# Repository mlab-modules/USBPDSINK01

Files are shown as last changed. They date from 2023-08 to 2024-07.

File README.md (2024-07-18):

# USBPDSINK01 - USB Power Delivery sink controller

The [MLAB](https://www.mlab.cz) module [USBPDSINK01](https://www.mlab.cz/module/USBPDSINK01) is a powerful module containing the [STUSB4500](https://www.st.com/en/interfaces-and-transceivers/stusb4500.html) [power-delivery sink controller](https://en.wikipedia.org/wiki/USB_hardware#USB_Power_Delivery). The module is designed to provide a flexible and reliable solution for various applications requiring USB power delivery PD2 and PD3 protocols. 

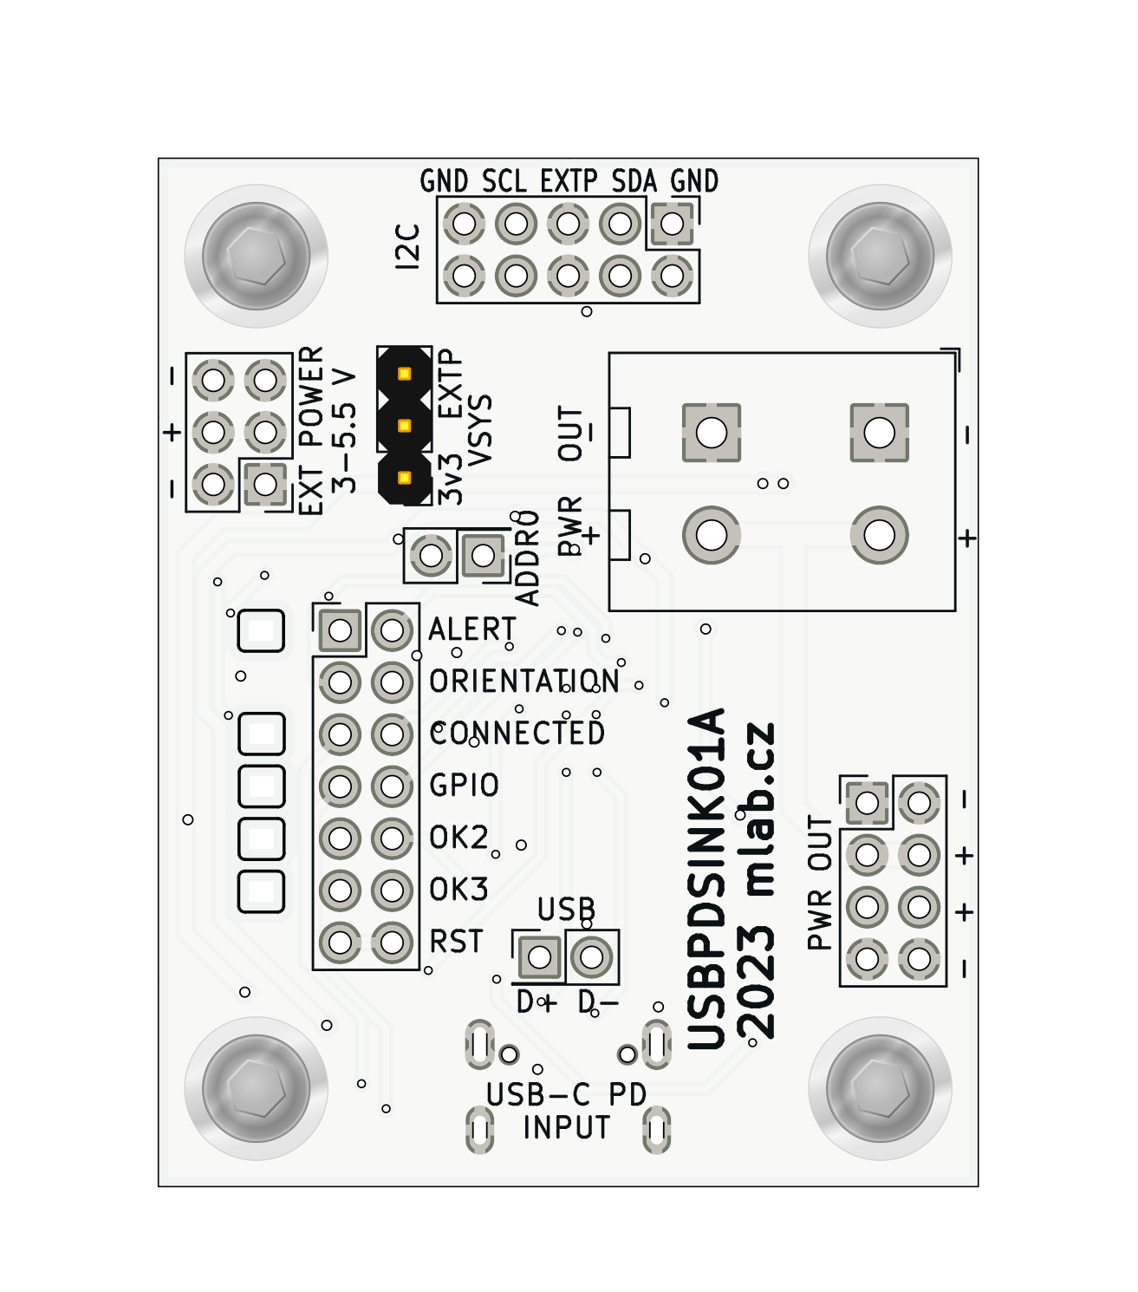
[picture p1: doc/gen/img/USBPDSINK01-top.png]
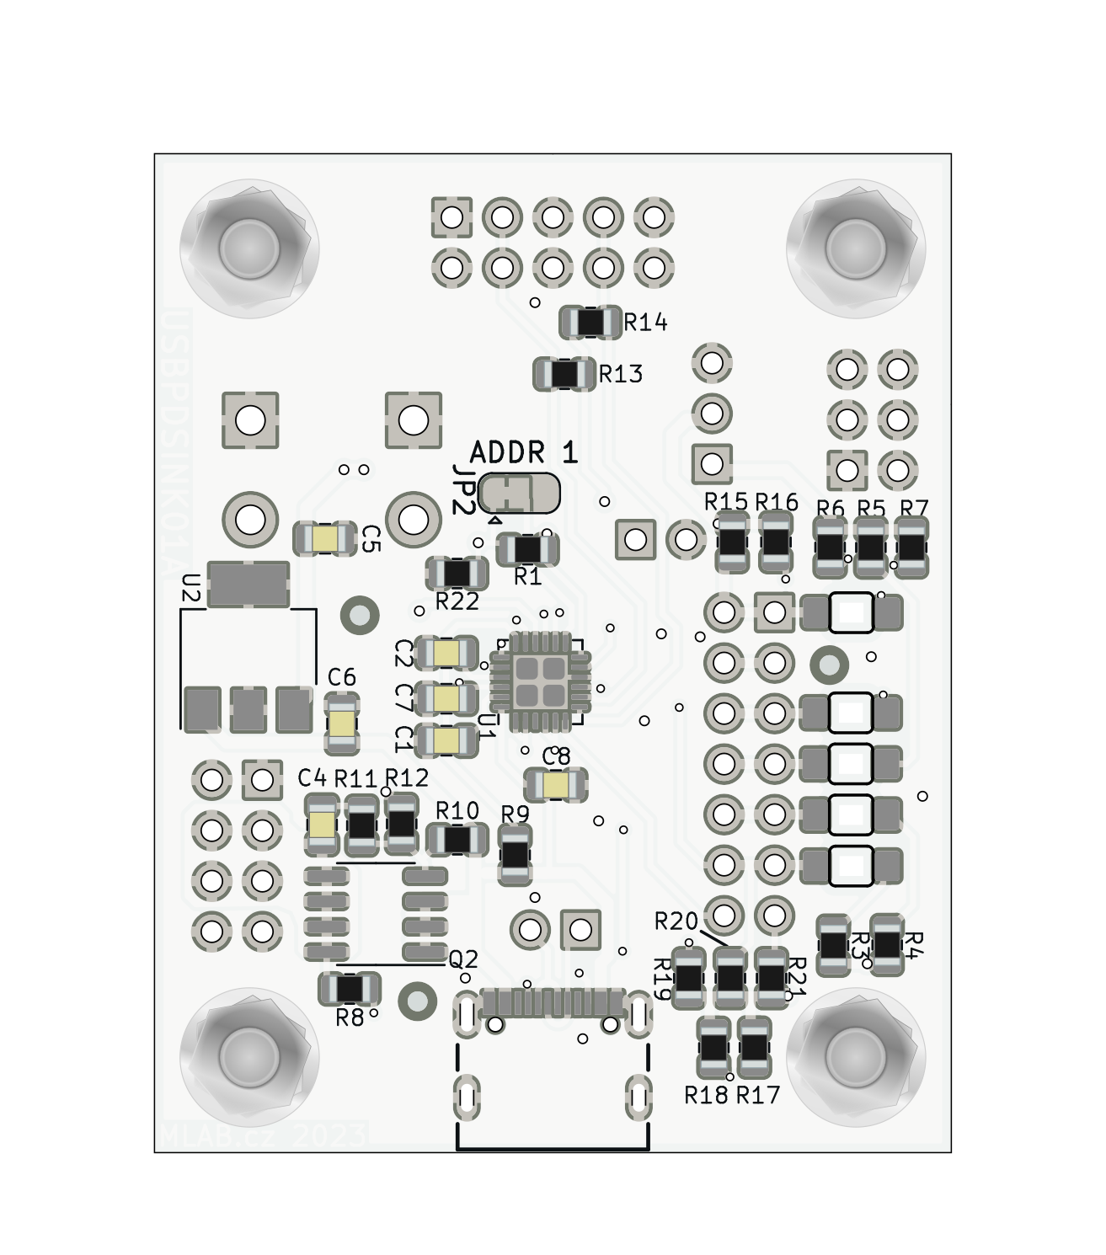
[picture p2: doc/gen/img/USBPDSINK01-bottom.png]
  

## Specifications

[STUSB4500](https://www.st.com/en/interfaces-and-transceivers/stusb4500.html) is a USB-C PD controller for Power Sinks / UFP (on the device side). It is certified by the USB-IF consortium for [USB Type-C](https://www.usb.org/usb-type-c) and [USB Power Delivery](https://www.usb.org/usb-charger-pd) applications (USB-C & USB PD).

### Module Features

- **USB-C Input:** The module accepts power through the USB-C connector.
- **Power Output:** The output is led to a pin header and also to a WAGO terminal block to high-power tool-free connection of powered devices.
- **Indicator Pins with LED:** Some status pins contain LEDs, and these signals are connected to the pin header.
- **Pull-up Resistors:** The module has pull-up resistors on the output signals for fast implementation into your system. PullUp voltage can be attached to header pins or can be used internal 3v3.
- **Integrated LDO:** The module is equipped with an integrated LDO for powering pullups and LED (no output).
- **External Power Supply:** The VSYS power can also be attached externally.
- **Communication via I2C:** The module communicates via I2C bus.
- **Key Features of [STUSB4500](https://www.st.com/en/interfaces-and-transceivers/stusb4500.html):**
  - Auto-run USB Type-C™ and USB PD sink controller handling and detection
  - Dead battery mode support
  - Up to 3 configurable sink PDO profiles (with permanent memory)
  - Integrated VBUS switching gates (PMOS transistor)
  - Integrated VBUS voltage monitoring
  - Internal and/or external VBUS discharge paths (for high capacitance networks)
  - Short-circuit protection on VBUS pins (22 V)
  - High-voltage capability on VBUS pins (28 V)
  - Dual power supply (VSYS and/or VDD): VDD = [4.1 V; 22 V] or VSYS = [3.0 V; 5.5 V]
  - Accessory mode support
  - Temperature range: -40 °C to 105 °C
  - ESD: 3 kV HBM - 1.5 kV CDM
  - Certified: USB Type-C™ rev 1.2, USB PD rev 2.0 (Official Test ID: TID #1000133)
  - Interoperable with USB PD rev 3.0

### Pinout and Their Meaning

- **ALERT:** Notification of various states and events.
- **USB-C orientation:** Indication of the connected side of the USB-C cable.
- **CONNECTED:** Cable connection indication.
- **GPIO:** General input/output pin, configurable for various purposes.
- **OK2 & OK3:** Pins that are active when the corresponding PDO is selected. Can indicate the selected voltage.
- **RESET:** Pin for resetting the USB-PD controller.

## Possible Applications
The MLAB module USBPDSINK01 is ideal for a wide range of applications, including:

- **Device Charging:** Fast and efficient charging of devices with high battery capacity. The module allows automatic negotiation of higher voltage from the source (>5V) up to 100W (20V@5A), ensuring the optimal charging profile for various types of batteries.

- **Scientific and Industrial Applications:** Flexible power and control for various scientific and industrial applications. With the ability to configure up to three sink PDO profiles, the module can be tailored to specific research or experiment needs.

- **Development and Testing:** The module can be used as part of development and testing stations for various products. With integrated VBUS switching gates and short-circuit protection up to 22 V, the module offers a robust and safe solution for testing and tuning.

- **Universal Power Source:** The module can serve as a universal power source for various devices, including charges, speakers, machines, or other electronic devices that require high-wattage power sources.

<p align="center">
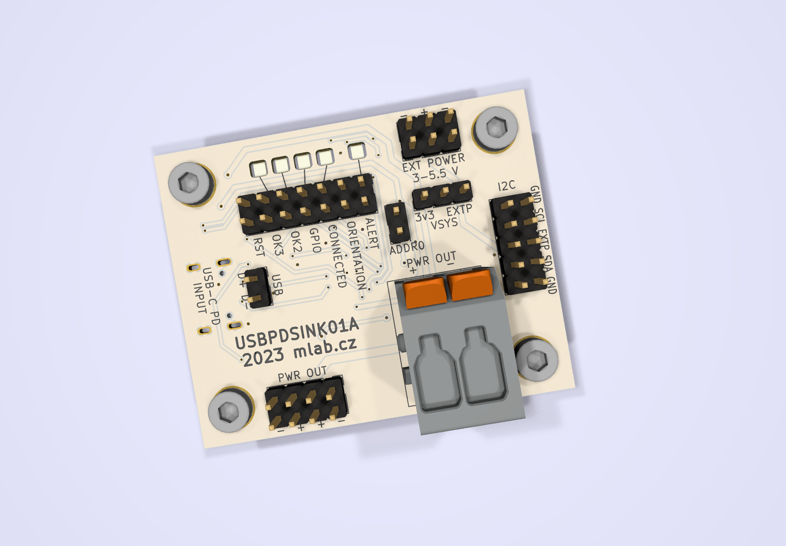
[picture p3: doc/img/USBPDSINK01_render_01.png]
 
</p>

## Schematics



## Documentation
- [STUSB4500 Datasheet](https://www.st.com/resource/en/datasheet/stusb4500.pdf)

## Conclusion

The MLAB module USBPDSINK01 represents a robust and flexible solution for various applications requiring USB power delivery. With the integrated STUSB4500 controller, advanced features, and a wide range of possible applications, this module is the ideal choice for developers and engineers looking for a reliable and powerful solution.

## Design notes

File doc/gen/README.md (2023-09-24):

# PCB

Board size: 45.49x52.95 mm (1.79x2.08 inches)

- This is the size of the rectangle that contains the board
- Thickness: 1.6 mm (63 mils)
- Material: FR4
- Finish: None
- Layers: 2
- Copper thickness: 35 µm

Solder mask: TOP / BOTTOM

- Color: Top: White / Bottom: Green

Silk screen: TOP / BOTTOM

- Color: Black

Stackup:

| Name | Type | Color | Thickness | Material | Epsilon_r | Loss tangent |
|---|---|---|---|---|---|---|
| F.SilkS | Top Silk Screen | Black | | | | |
| F.Paste | Top Solder Paste | | | | | |
| F.Mask | Top Solder Mask | White | 10 | | | |
| F.Cu | copper | | 35 | | | |
| dielectric 1 | core | FR4 natural | 1510 | FR4 | 4.5 | 0.020 |
| B.Cu | copper | | 35 | | | |
| B.Mask | Bottom Solder Mask | Green | 10 | | | |
| B.Paste | Bottom Solder Paste  | | | | | |
| B.SilkS | Bottom Silk Screen | Black | | | | |

# Important sizes

Clearance: 0.2 mm (8 mils)

Track width: 0.25 mm (10 mils)

- By design rules: 0.0 mm (0 mils)

Drill: 0.4 mm (16 mils)

- Vias: 0.4 mm (16 mils) [Design: 0.4 mm (16 mils)]
- Pads: 0.65 mm (26 mils)
- The above values are real drill sizes, they add 0.1 mm (4 mils) to plated holes (PTH)

Via: 0.5/0.3 mm (20/12 mils)

- By design rules: 0.5/0.3 mm (20/12 mils)
- Micro via: yes [0.2/0.1 mm (8/4 mils)]
- Buried/blind via: yes
- Total: 48 (thru: 48 buried/blind: 0 micro: 0)

Outer Annular Ring: 0.05 mm (2 mils)

- By design rules: 0.05 mm (2 mils)

Eurocircuits class: 6D
- Using min drill 0.25 mm for an OAR of 0.13 mm

# General stats

Components count: (SMD/THT)

- Top: 0/12 (THT)
- Bottom: 40/0 (SMD)

Defined tracks:

- 0.25 mm (10 mils)
- 0.3 mm (12 mils)
- 0.5 mm (20 mils)
- 0.6 mm (24 mils)

Used tracks:

- 0.25 mm (10 mils) (59) defined: yes
- 0.3 mm (12 mils) (174) defined: yes
- 0.5 mm (20 mils) (37) defined: yes
- 0.6 mm (24 mils) (44) defined: yes
- 1.0 mm (39 mils) (4) defined: no

Defined vias:

- 0.5/0.3 mm (20/12 mils)
- 0.8/0.4 mm (31/16 mils)

Used vias:

- 0.5/0.3 mm (20/12 mils) (Count: 28, Aspect: 3.2 A) defined: yes
- 0.8/0.4 mm (31/16 mils) (Count: 20, Aspect: 2.0 A) defined: yes

Holes (excluding vias):

- 0.65 mm (26 mils) (2)
- 1.0 mm (39 mils) (45)
- 1.4 mm (55 mils) (4)
- 3.0 mm (118 mils) (4)

Oval holes:

- 0.6x1.4 mm (24x55 mils) (2)
- 0.6x1.7 mm (24x67 mils) (2)

Drill tools (including vias and computing adjusts and rounding):

- 0.4 mm (16 mils) (28)
- 0.5 mm (20 mils) (20)
- 0.65 mm (26 mils) (2)
- 0.7 mm (28 mils) (4)
- 1.1 mm (43 mils) (45)
- 1.5 mm (59 mils) (4)
- 3.1 mm (122 mils) (4)

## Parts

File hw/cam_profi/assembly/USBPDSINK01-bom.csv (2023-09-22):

Component | Description | Part | References | Value | Footprint | Quantity Per PCB | Datasheet | mfpn | mpn | ust_id | sim.pins | sim.type
1 | Unpolarized capacitor, small symbol | C_Small | C4 | 100n | C_0805_2012Metric | 1 | ~ | C0805 100n | C0805 100n | 5c70984712875079b91f8b4c
2 | Unpolarized capacitor, small symbol | C_Small | C1C2C7C8 | 1u | C_0805_2012Metric | 4 | ~ | C0805 1u | C0805 1u | 5c70984712875079b91f8b50
3 | Unpolarized capacitor, small symbol | C_Small | C5C6 | 10u | C_0805_2012Metric | 2 | ~ | C0805 10u | C0805 10u | 5c70984712875079b91f8b53
4 | Light emitting diode | LED | D3 | BLUE | LED_1206_mill | 1 | ~ | KPTR-3216QBC-D | KPTR-3216QBC-D | 650b4b9e462c6d9e7205459d
5 | Light emitting diode | LED | D5 | GREEN | LED_1206_mill | 1 | ~ | KPTR-3216CGCK | KPTR-3216CGCK | 64ab2ec176c82a1d3b57875b
6 | Light emitting diode | LED | D1D4 | RED | LED_1206_mill | 2 | ~ | KPTR-3216SURCK | KPTR-3216SURCK | 64ab2fba76c82a1d3b57877d
7 | Light emitting diode | LED | D2 | YELLOW | LED_1206_mill | 1 | ~ | KPTR-3216SYCK | KPTR-3216SYCK | 650b4b13462c6d9e7205456a
8 | 2x03 2.54 mm pitch header, 2 pins next to each other are connected | HEADER_2x03_PARALLEL | J4 | HEADER_2x03_PARALLEL | PinHeader_2x03_P2.54mm_Vertical | 1
9 | 2x04 2.54 mm pitch header, 2 pins next to each other are connected | HEADER_2x04_PARALLEL | J3 | HEADER_2x04_PARALLEL | PinHeader_2x04_P2.54mm_Vertical | 1
10 | 2x05 2.54 mm pitch header, 2 pins next to each other are connected | HEADER_2x05_PARALLEL | J2 | HEADER_2x05_PARALLEL | PinHeader_2x05_P2.54mm_Vertical | 1
11 | 2x07 2.54 mm pitch header, 2 pins next to each other are connected | HEADER_2x07_PARALLEL | J6 | HEADER_2x07_PARALLEL | PinHeader_2x07_P2.54mm_Vertical | 1
12 | USB 2.0-only Type-C Receptacle connector | USBC_USB4105-GF-A | J1 | USBC_USB4105-GF-A | USBC GCT_USB4105-GF-A | 1 |  | USB4105-GF-A | USB4105-GF-A | 5fa0f94612875025b397795e
13 | 1x02 2.54 mm pitch header | HEADER_1x02 | J7 | WAGO_2604-3102 | TerminalBlock_WAGO_2604-3102_1x02_P5.00mm_Vertical | 1 |  | 2604-3102 | 2604-3102
14 | Jumper, 2-pole, open | Jumper_2_Open | JP1 | Jumper_2_Open | PinHeader_2x01_P2.54mm_Vertical | 1 | ~
15 | Jumper, 3-pole, pins 1+2 closed/bridged | Jumper_3_Bridged12 | JP2 | Jumper_3_Bridged12 | SolderJumper-3_P1.3mm_Bridged12_RoundedPad1.0x1.5mm | 1 | ~
16 | Jumper, 3-pole, pins 1+2 closed/bridged | Jumper_3_Bridged12 | JP3 | Jumper_3_Bridged12 | PinHeader_1x03_P2.54mm_Vertical | 1 | ~
17 | P-MOSFET transistor, drain/source/gate, 40V, 9A, 12mOhm | IRF7469PbF | Q2 | IRF9317TRPBF | SOIC-8_3.9x4.9mm_P1.27mm | 1 |  | IRF9317TRPBF | IRF9317TRPBF | 64f8de80f3b9d36f37fc9304 | 1=D 2=G 3=S | VDMOS
18 | Resistor, small symbol | R_Small | R4 | 10R | R_0805_2012Metric | 1 | ~ | R0805 10R 1% | R0805 10R 1% | 5c70984512875079b91f896d
19 | Resistor, small symbol | R_Small | R3R5R6R7 | 62R | R_0805_2012Metric | 4 | ~ | R0805 62R 1% | R0805 62R 1% | 5c70984512875079b91f8974
20 | Resistor, small symbol | R_Small | R11 | 100R | R_0805_2012Metric | 1 | ~ | R0805 100R 1% | R0805 100R 1% | 5c70984512875079b91f8977
21 | Resistor, small symbol | R_Small | R8R9 | 1k | R_0805_2012Metric | 2 | ~ | R0805 1k 1% | R0805 1k 1% | 5c70984512875079b91f898c
22 | Resistor, small symbol | R_Small | R13R14R15R16R17R18R19R20R21 | 4k7 | R_0805_2012Metric | 9 | ~ | R0805 4k7 1% | R0805 4k7 1% | 5c70984612875079b91f8995
23 | Resistor, small symbol | R_Small | R12 | 20k | R_0805_2012Metric | 1 | ~ | R0805 20k 1% | R0805 20k 1% | 5c70984612875079b91f89a3
24 | Resistor, small symbol | R_Small | R1R10R22 | 100k | R_0805_2012Metric | 3 | ~ | R0805 100K 1% | R0805 100K 1% | 639ed3d540d28a66c9e88a9e
25 | 50mA Ultra-Low Quiescent Current LDO Voltage Regulator, 3.3V fixed output, TO-252/SOT-223 | LM2936-3.3 | U2 | NCV4274CST33T3G | SOT-223-3_TabPin2 | 1 | https://cz.mouser.com/datasheet/2/308/1/NCV4274C_D-2317600.pdf | NCV4274CST33T3G | NCV4274CST33T3G | 650b45d7462c6d9e720544df
26 | Stand-alone USB PD controller (with sink Auto-run mode), QFN-24 | STUSB4500QTR | U1 | STUSB4500QTR | QFN-24-1EP_4x4mm_P0.5mm_EP2.7x2.7mm | 1 | https://www.st.com/resource/en/datasheet/stusb4500.pdf | STUSB4500QTR | STUSB4500QTR | 64f8daa2f3b9d36f37fc92aa

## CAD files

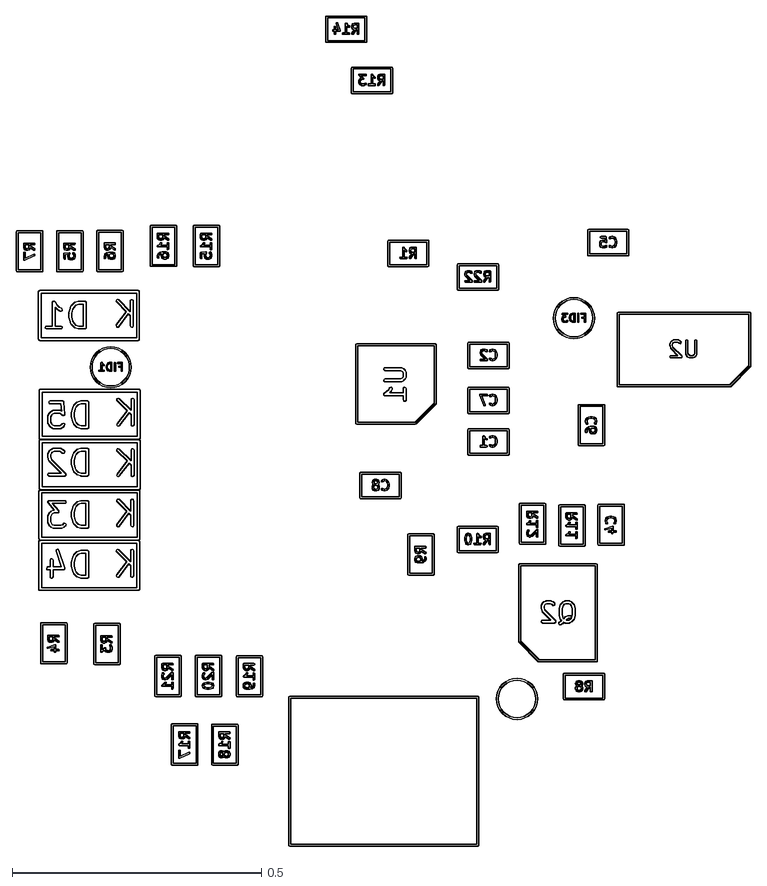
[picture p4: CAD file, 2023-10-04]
doc/gen/dxf/USBPDSINK01-B_Fab.dxf
1.47 x 1.66

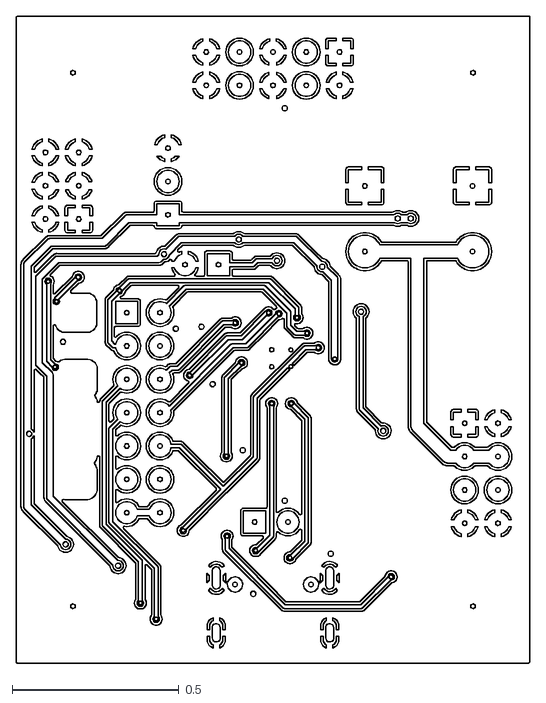
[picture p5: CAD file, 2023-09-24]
doc/gen/dxf/USBPDSINK01-F_Cu.dxf
1.54 x 1.94

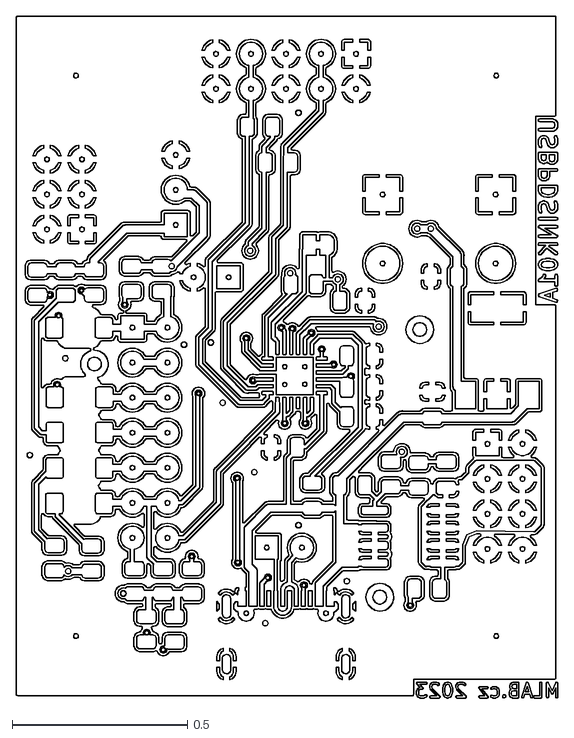
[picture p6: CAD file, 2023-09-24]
doc/gen/dxf/USBPDSINK01-B_Cu.dxf
1.55 x 1.95

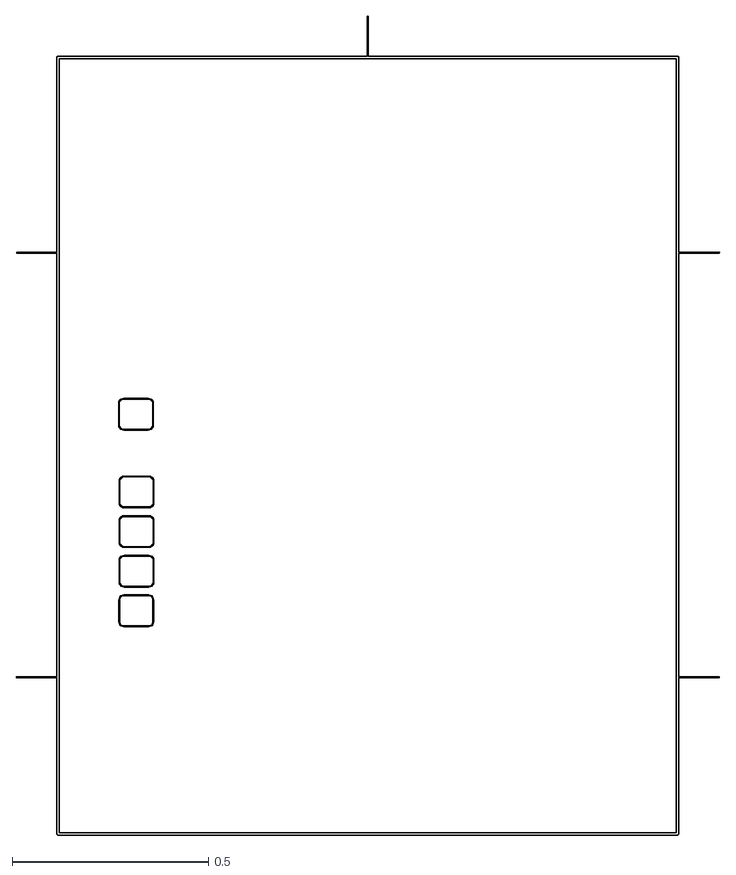
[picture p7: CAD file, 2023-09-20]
doc/gen/dxf/USBPDSINK01-Edge_Cuts.dxf
1.79 x 2.09

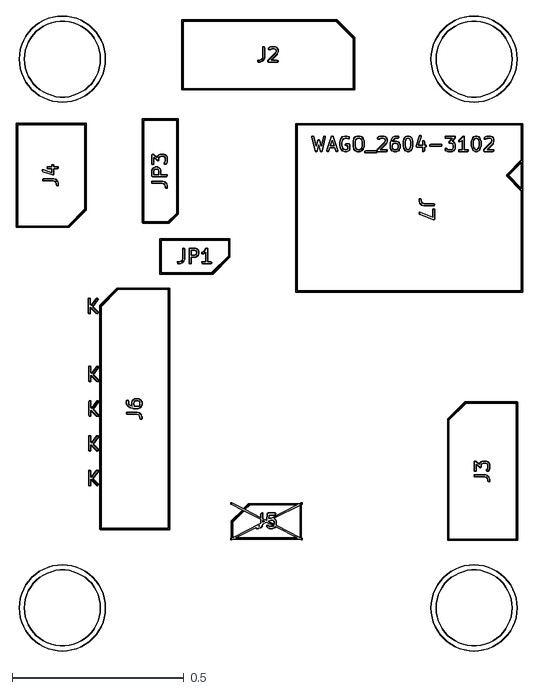
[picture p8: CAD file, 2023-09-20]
doc/gen/dxf/USBPDSINK01-F_Fab.dxf
1.48 x 1.85

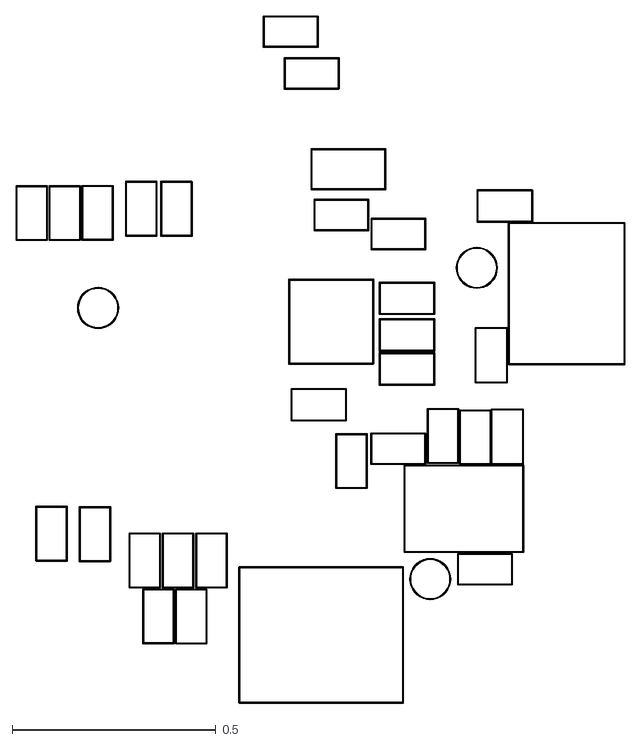
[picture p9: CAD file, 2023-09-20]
doc/gen/dxf/USBPDSINK01-B_Courtyard.dxf
1.49 x 1.69

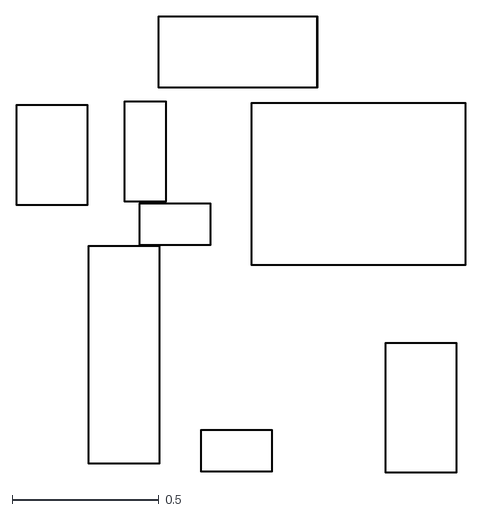
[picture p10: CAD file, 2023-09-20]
doc/gen/dxf/USBPDSINK01-F_Courtyard.dxf
1.53 x 1.56

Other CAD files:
doc/gen/dxf/USBPDSINK01-B_Adhesive.dxf
doc/gen/dxf/USBPDSINK01-User_Eco2.dxf
doc/gen/dxf/USBPDSINK01-Margin.dxf
doc/gen/dxf/USBPDSINK01-User_Comments.dxf
doc/gen/dxf/USBPDSINK01-User_Drawings.dxf
doc/gen/dxf/USBPDSINK01-F_Adhesive.dxf
doc/gen/dxf/USBPDSINK01-User_Eco1.dxf
doc/gen/dxf/USBPDSINK01-B_Mask.dxf
doc/gen/dxf/USBPDSINK01-B_Paste.dxf
doc/gen/dxf/USBPDSINK01-B_Silkscreen.dxf
doc/gen/dxf/USBPDSINK01-F_Mask.dxf
doc/gen/dxf/USBPDSINK01-F_Paste.dxf
doc/gen/dxf/USBPDSINK01-F_Silkscreen.dxf

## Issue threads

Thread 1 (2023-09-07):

LDO input voltage handling

kaklik, 2023-09-07:
VE schéma vidím tohle zapojení.

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

Zdá se, že VBUS je připojený rovnou na vstupní napájení z USB. Maximální vstupní napětí tohoto LDO regulátoru je ale podle datasheetu 20V. Specifikace PD3, kterou Sink controller zřejmě umožňuje ale umí až 28V. Povožuji tak za poměrně pravděpodobné, že se takhle ten LDO zničí.

roman-dvorak, 2023-09-07:
Ne, tento PD kontrolér je specifikace PD2 s tím, že PD3 je zpětně kompatibilní. PD3 je e rozšířené o vyšší napětí/výkon (a možná něco dalšího). PD kontrolér se umí domluvit na napětí maximálně 20V. Vyšší napětí by se tam nemělo objevit, pokud nenastane nějaká chyba ve zdroji.

kaklik, 2023-09-07:
> Ne, tento PD kontrolér je specifikace PD2 s tím, že PD3 je zpětně kompatibilní. PD3 je e rozšířené o vyšší napětí/výkon (a možná něco dalšího). PD kontrolér se umí domluvit na napětí maximálně 20V. Vyšší napětí by se tam nemělo objevit, pokud nenastane nějaká chyba ve zdroji.

Dobře, ale i tak je to bez rezervy. Chápu, že sehnat 3.3V stabilizátor z 20 V je komplikace. Nejde na to ale zvolit nějaký lepší technický přístup? Například tam mít nejdříve stabilizátor na 5V a z něj teprve dělat tohle nízké napětí?

roman-dvorak, 2023-09-07:
Tenhle přístup má problém, že rozsah možných napětí je 5V (4.5V??) - 20V. Což je pod hranicí 5V LDO. Můžu se ještě podívat po jiných LDO, které poskytují větší provozní rozsah.

ChroustJan, 2023-09-22:
Byl použit obvod NCV4274CST33T3G, který umožňuje až 40 V na svém vstupu.

Closed 2023-09-22.

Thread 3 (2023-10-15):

3V3 short-circuit by via

kaklik, 2023-10-15:
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

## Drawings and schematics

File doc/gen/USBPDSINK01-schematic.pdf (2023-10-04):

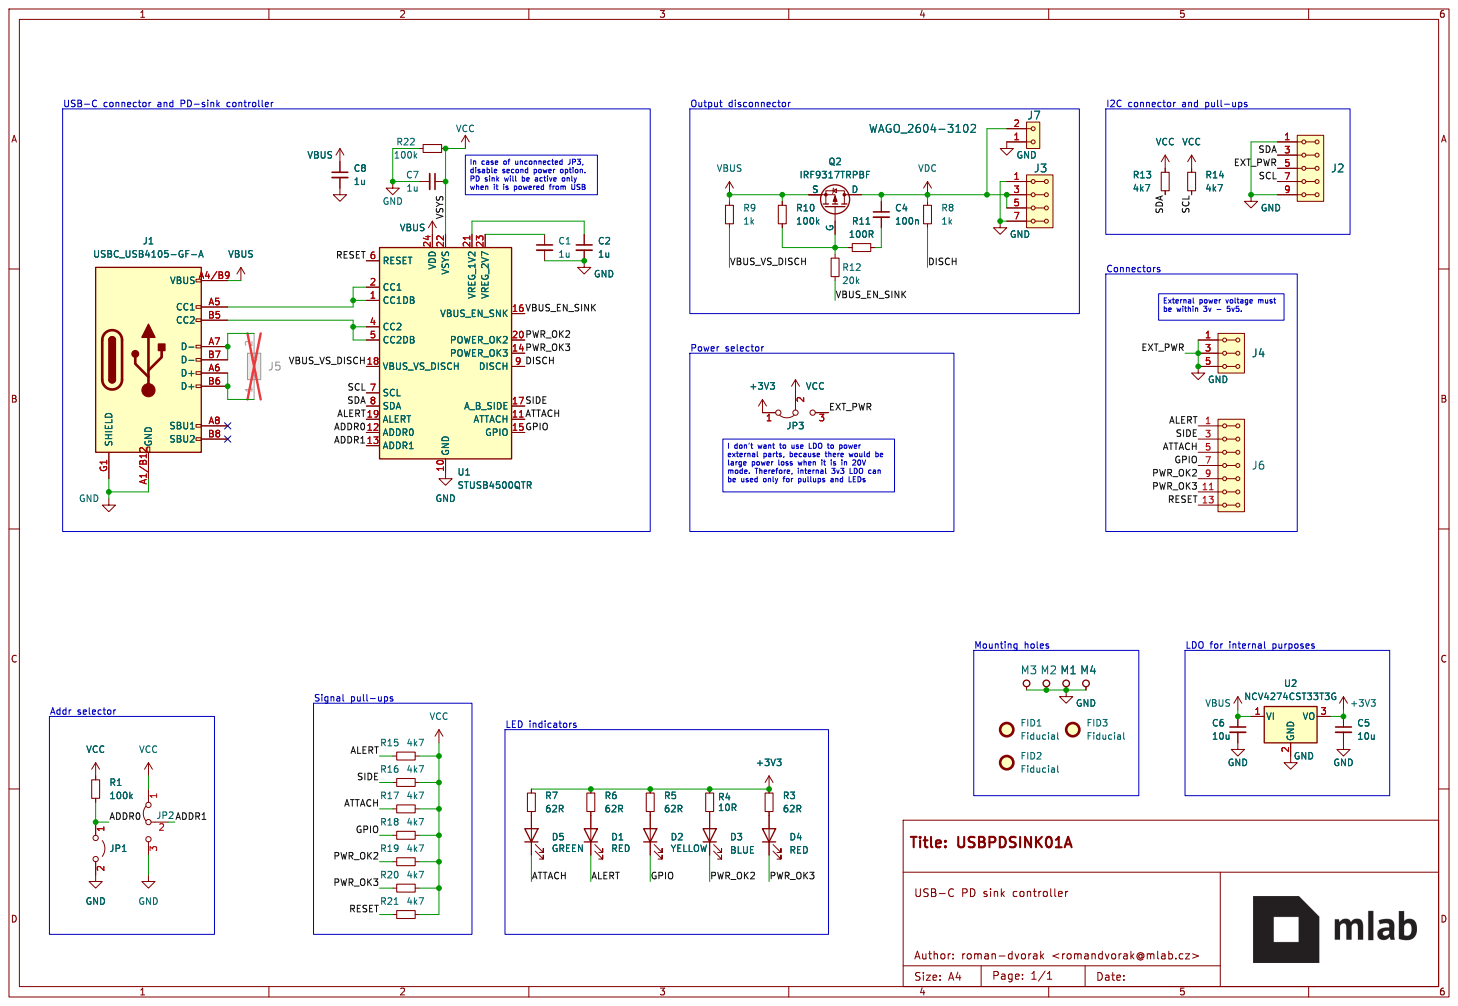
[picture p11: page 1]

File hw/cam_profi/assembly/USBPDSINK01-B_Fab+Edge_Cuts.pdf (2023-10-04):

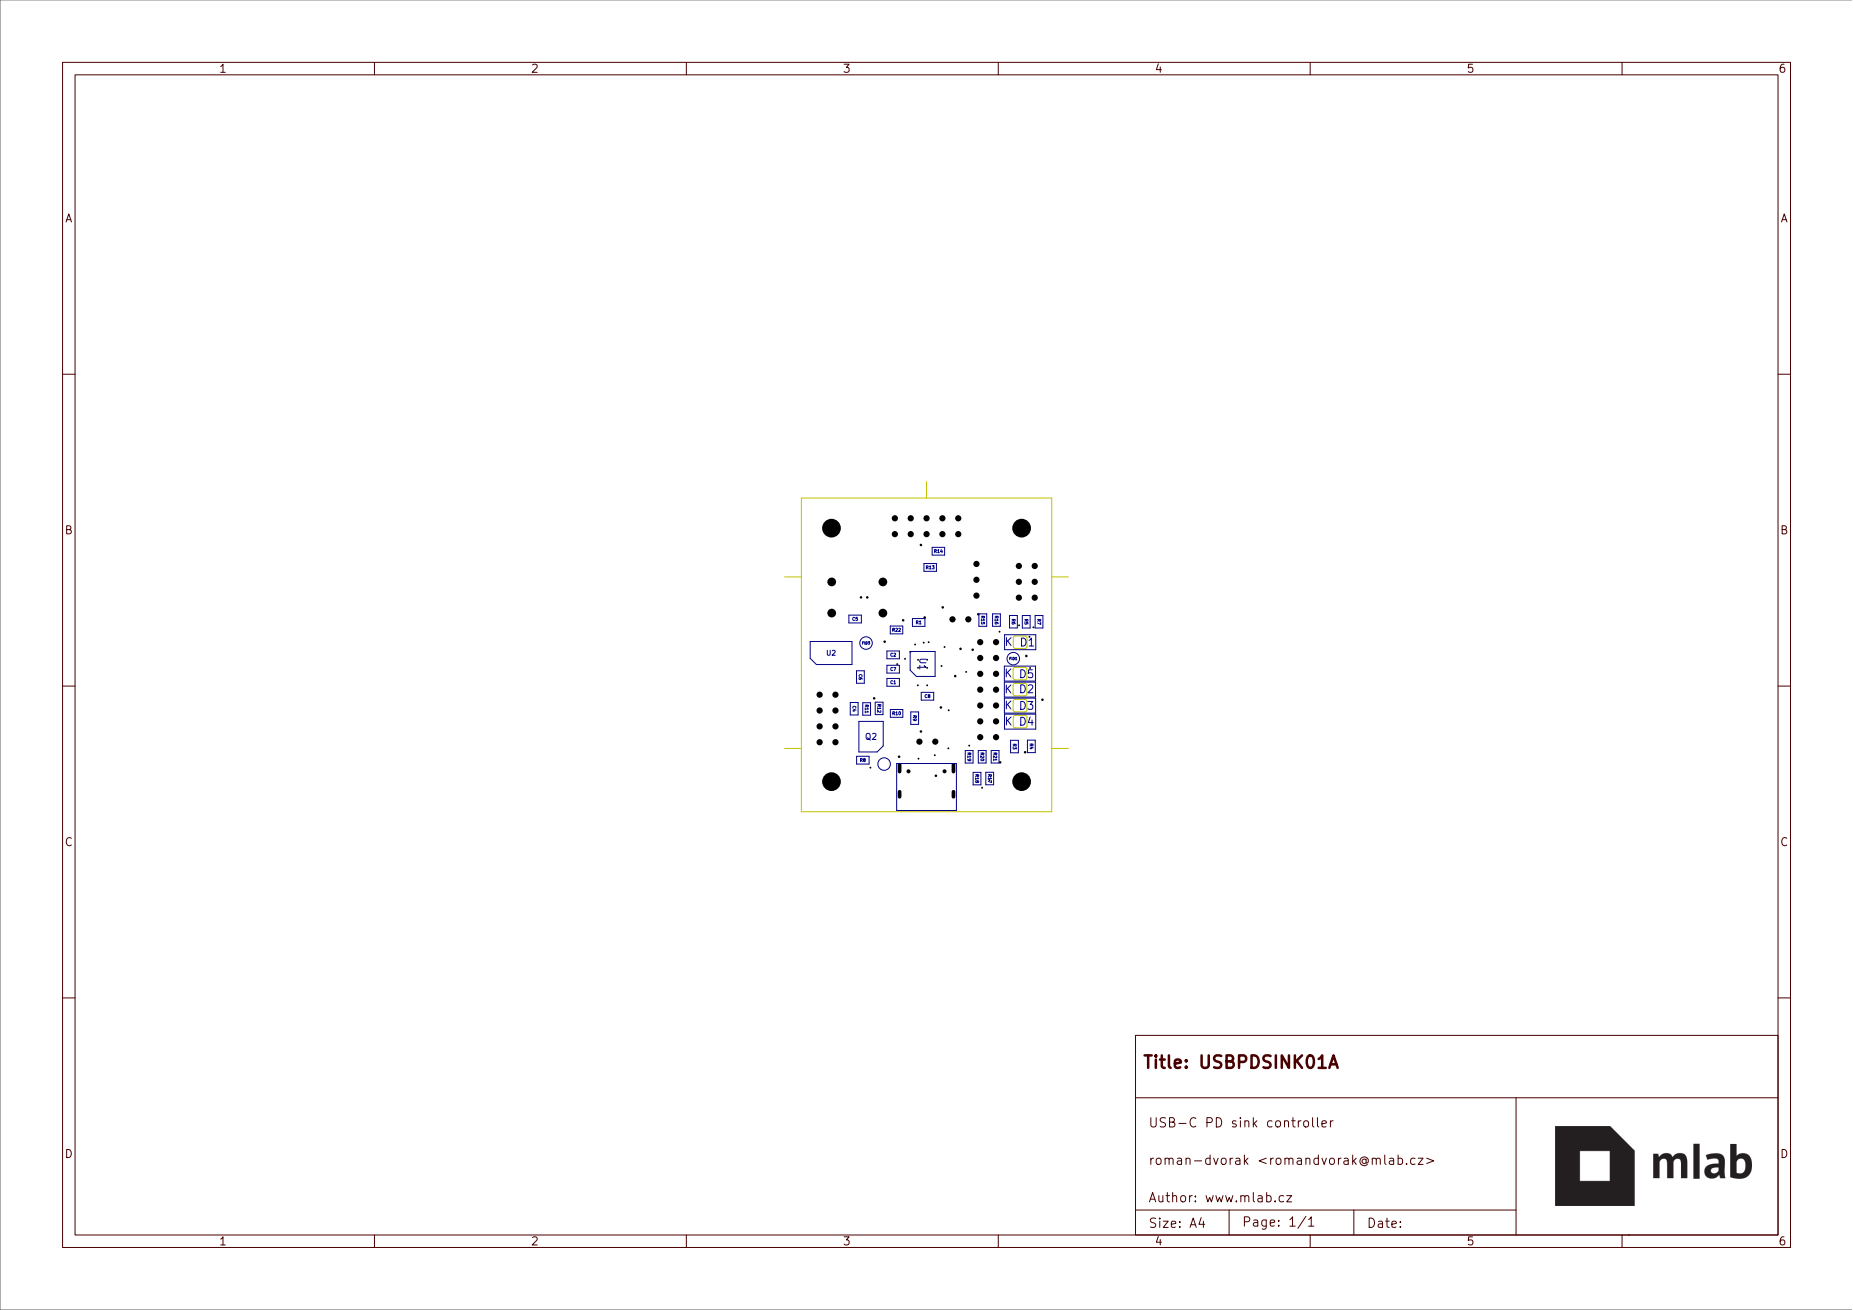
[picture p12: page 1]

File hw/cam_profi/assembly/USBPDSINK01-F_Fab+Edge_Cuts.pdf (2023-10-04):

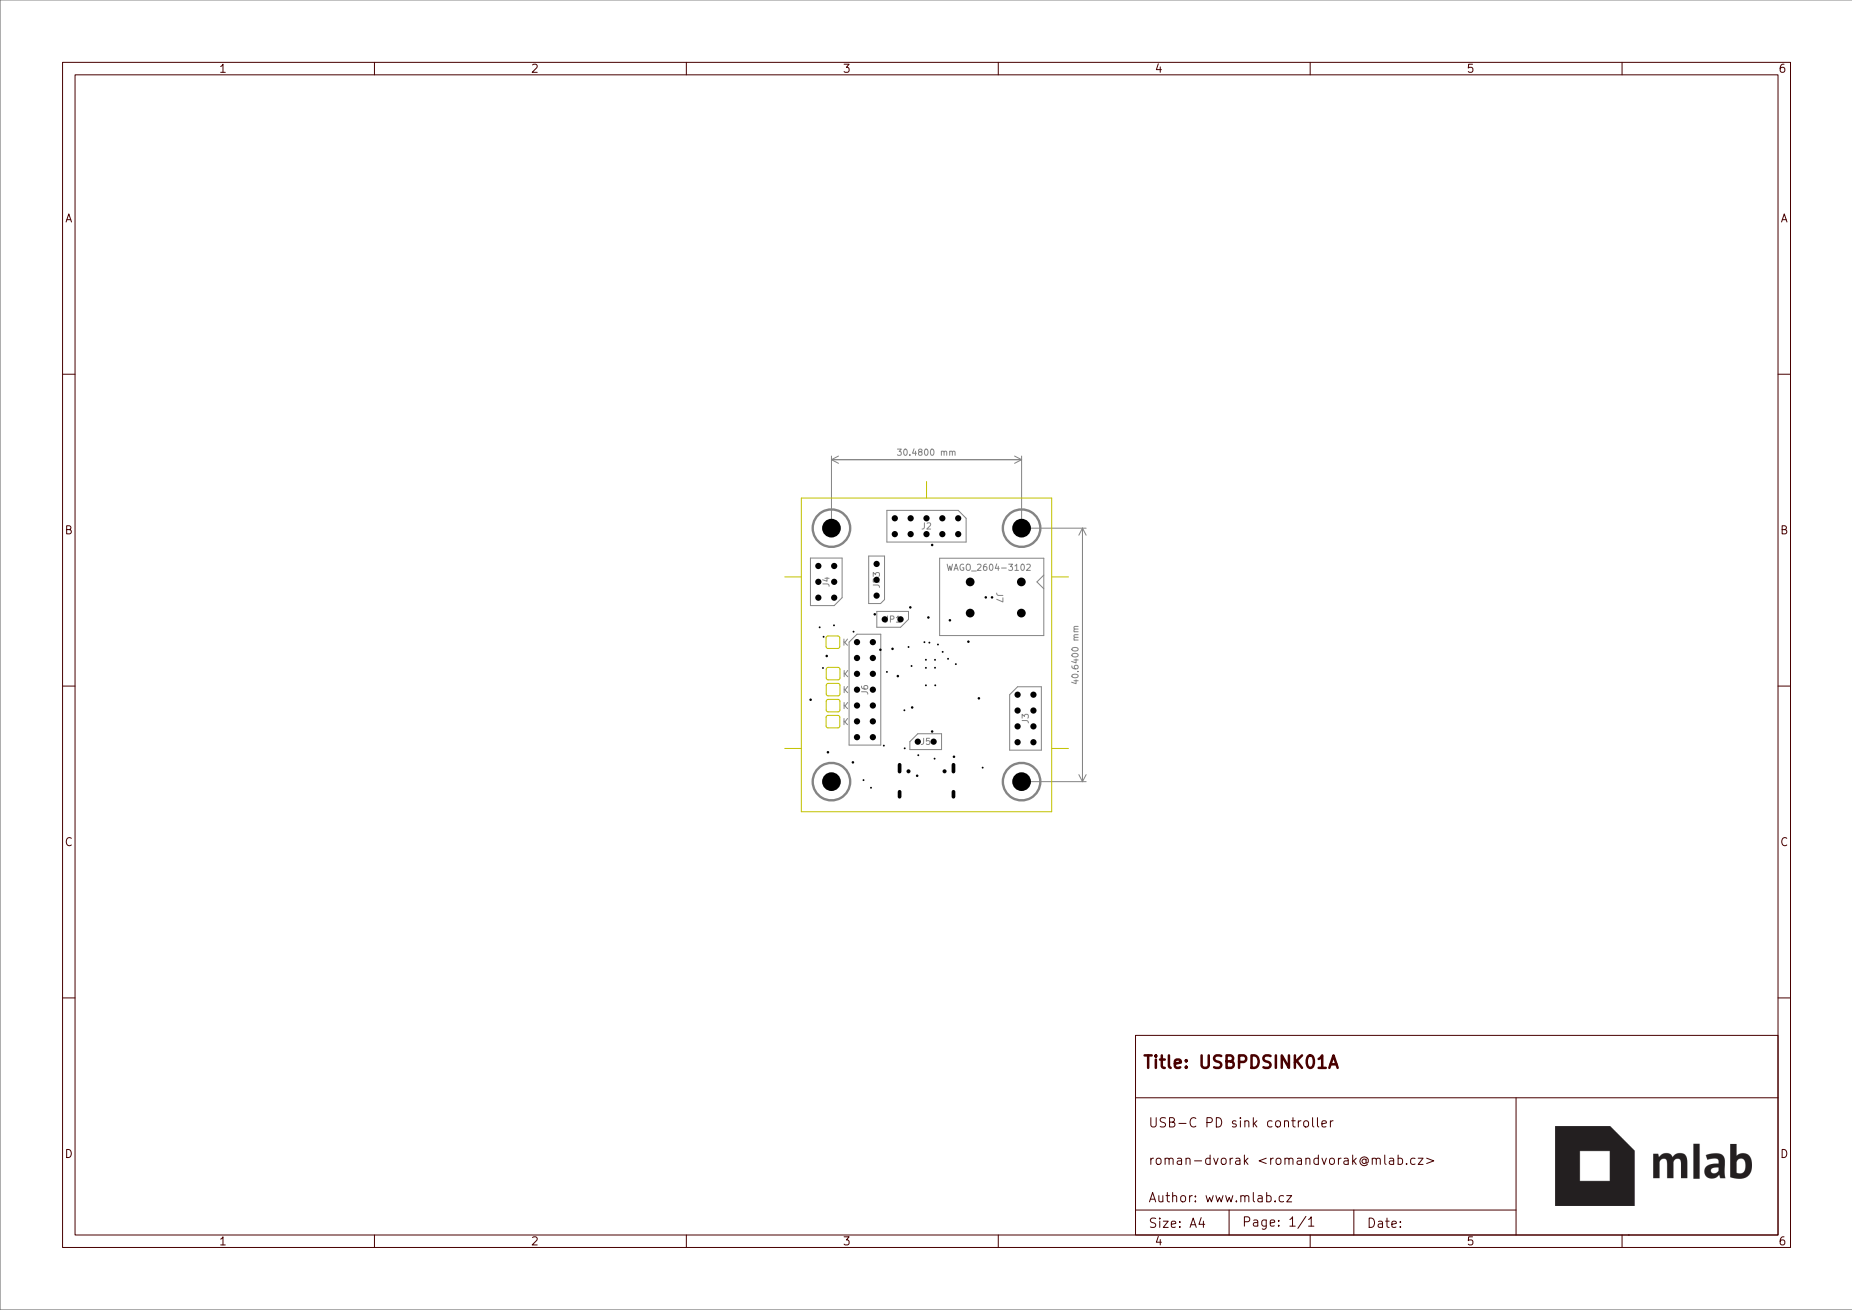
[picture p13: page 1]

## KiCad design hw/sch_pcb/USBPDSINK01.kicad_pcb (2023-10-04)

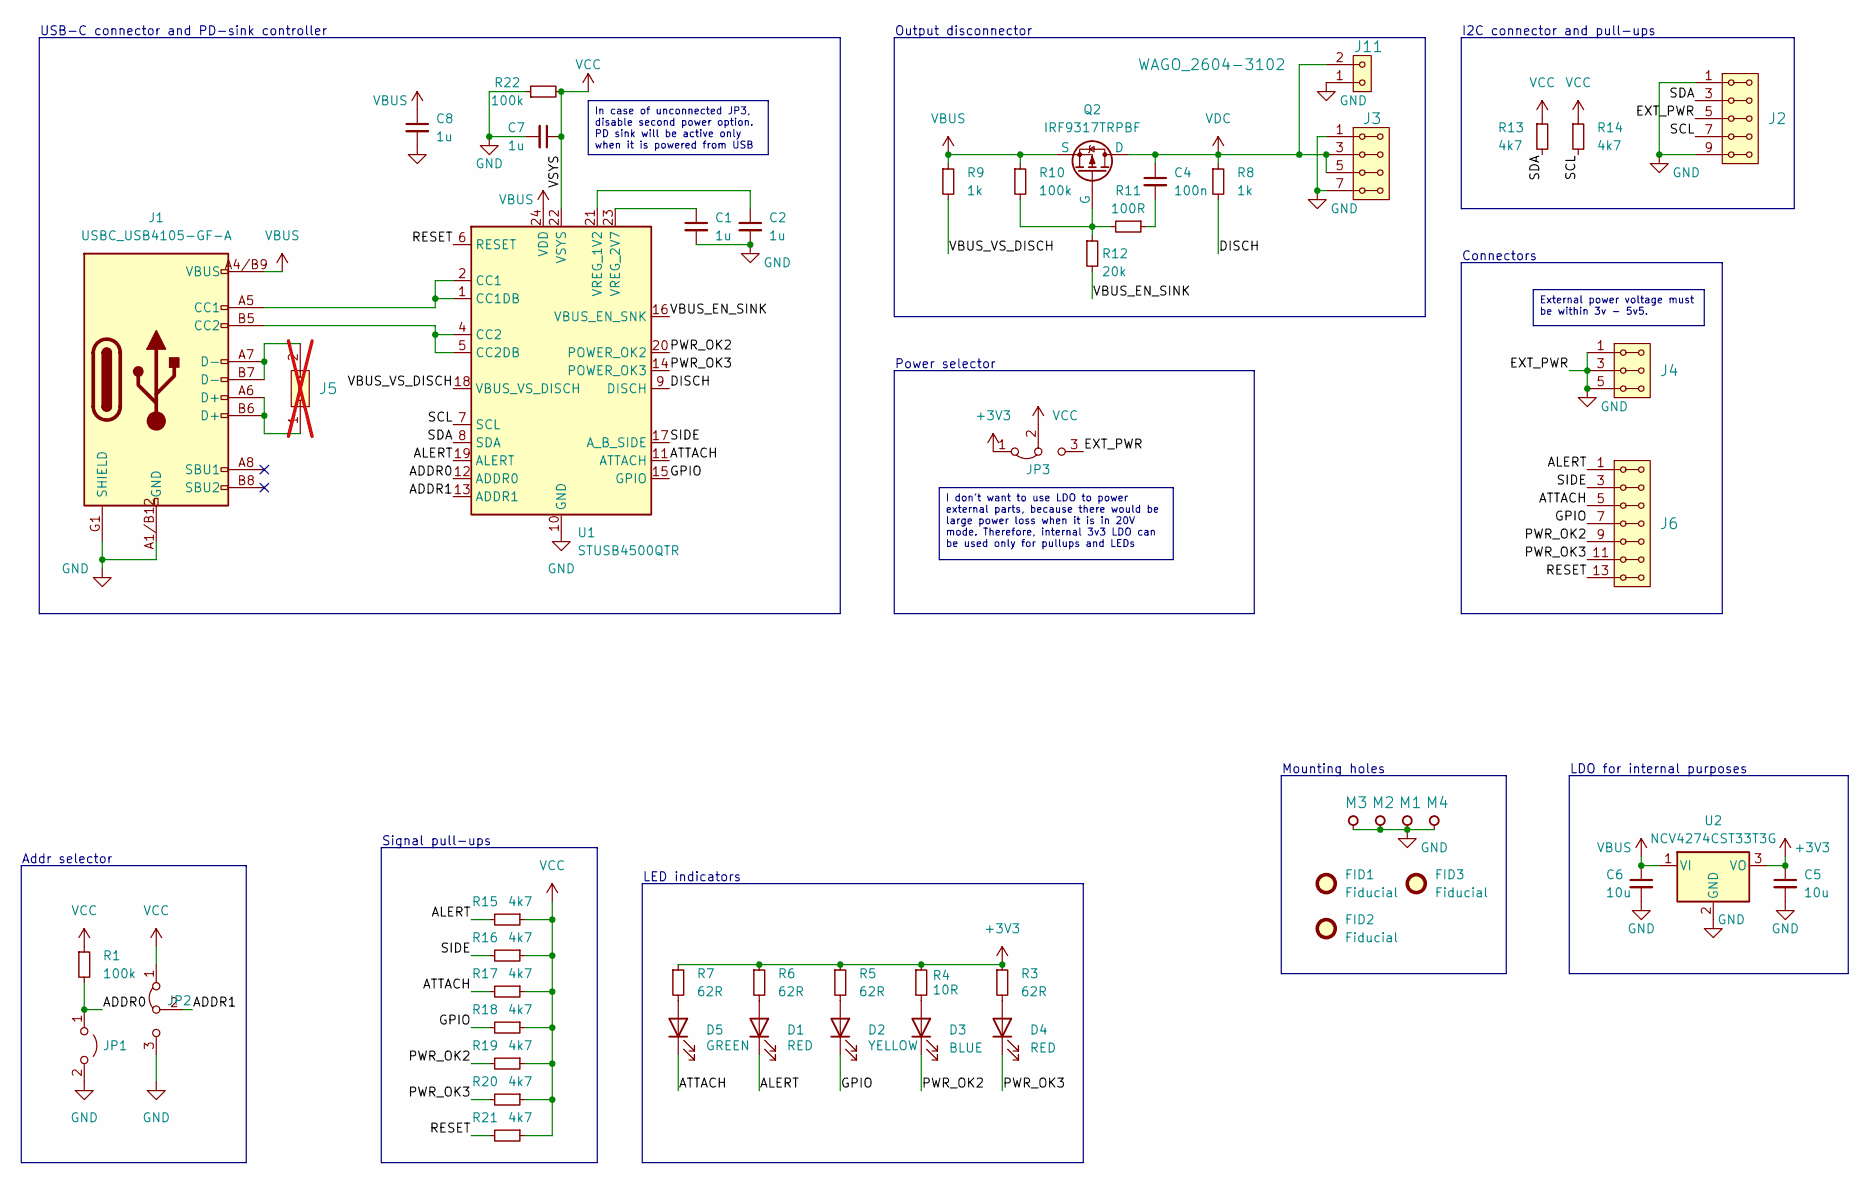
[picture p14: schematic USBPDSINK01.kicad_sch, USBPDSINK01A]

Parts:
C1, C2, C7, C8: 1u; C_0805_2012Metric; MPN C0805 1u
C4: 100n; C_0805_2012Metric; MPN C0805 100n
C5, C6: 10u; C_0805_2012Metric; MPN C0805 10u
D1, D4: RED; LED_1206_mill; MPN KPTR-3216SURCK
D2: YELLOW; LED_1206_mill; MPN KPTR-3216SYCK
D3: BLUE; LED_1206_mill; MPN KPTR-3216QBC-D
D5: GREEN; LED_1206_mill; MPN KPTR-3216CGCK
FID1, FID2, FID3: Fiducial; Fiducial_1mm_Mask2mm
J1: USBC_USB4105-GF-A; USBC GCT_USB4105-GF-A; MPN USB4105-GF-A
J2: HEADER_2x05_PARALLEL; PinHeader_2x05_P2.54mm_Vertical
J3: HEADER_2x04_PARALLEL; PinHeader_2x04_P2.54mm_Vertical
J4: HEADER_2x03_PARALLEL; PinHeader_2x03_P2.54mm_Vertical
J5: HEADER_2x01; PinHeader_2x01_P2.54mm_Vertical; not fitted
J6: HEADER_2x07_PARALLEL; PinHeader_2x07_P2.54mm_Vertical
J11: WAGO_2604-3102; TerminalBlock_WAGO_2604-3102_1x02_P5.00mm_Vertical; MPN 2604-3102
JP1: Jumper_2_Open; PinHeader_2x01_P2.54mm_Vertical
JP2: Jumper_3_Bridged12; SolderJumper-3_P1.3mm_Bridged12_RoundedPad1.0x1.5mm
JP3: Jumper_3_Bridged12; PinHeader_1x03_P2.54mm_Vertical
M1, M2, M3, M4: HOLE; MountingHole_3mm
Q2: IRF9317TRPBF; SOIC-8_3.9x4.9mm_P1.27mm; MPN IRF9317TRPBF
R1, R10, R22: 100k; R_0805_2012Metric; MPN R0805 100K 1%
R3, R5, R6, R7: 62R; R_0805_2012Metric; MPN R0805 62R 1%
R4: 10R; R_0805_2012Metric; MPN R0805 10R 1%
R8, R9: 1k; R_0805_2012Metric; MPN R0805 1k 1%
R11: 100R; R_0805_2012Metric; MPN R0805 100R 1%
R12: 20k; R_0805_2012Metric; MPN R0805 20k 1%
R13, R14, R15, R16, R17, R18, R19, R20, R21: 4k7; R_0805_2012Metric; MPN R0805 4k7 1%
U1: STUSB4500QTR; QFN-24-1EP_4x4mm_P0.5mm_EP2.7x2.7mm; MPN STUSB4500QTR
U2: NCV4274CST33T3G; SOT-223-3_TabPin2; MPN NCV4274CST33T3G

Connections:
+3V3: C5.1, JP3.1 (A), R3.1, R4.1, R5.1, R6.1, R7.1, U2.3 (VO)
/ADDR0: JP1.1 (A), R1.2, U1.12 (ADDR0)
/ADDR1: JP2.2 (C), U1.13 (ADDR1)
/ALERT: D1.1 (K), J6.1, J6.2, R15.2, U1.19 (ALERT)
/ATTACH: D5.1 (K), J6.5, J6.6, R17.2, U1.11 (ATTACH)
/DISCH: R8.2, U1.9 (DISCH)
/GPIO: D2.1 (K), J6.7, J6.8, R18.2, U1.15 (GPIO)
/PWR_OK2: D3.1 (K), J6.9, J6.10, R19.2, U1.20 (POWER_OK2)
/PWR_OK3: D4.1 (K), J6.11, J6.12, R20.2, U1.14 (POWER_OK3)
/RESET: J6.13, J6.14, R21.2, U1.6 (RESET)
/SCL: J2.7, J2.8, R14.2, U1.7 (SCL)
/SDA: J2.3, J2.4, R13.2, U1.8 (SDA)
/SIDE: J6.3, J6.4, R16.2, U1.17 (A_B_SIDE)
/VBUS_EN_SINK: R12.2, U1.16 (VBUS_EN_SNK)
/VBUS_VS_DISCH: R9.2, U1.18 (VBUS_VS_DISCH)
GND: C1.2, C2.2, C5.2, C6.2, C7.2, C8.2, J1.A1/B12 (GND), J1.B1/A12 (GND), J1.G1 (SHIELD), J1.G2 (SHIELD), J1.G3 (SHIELD), J1.G4 (SHIELD), J2.1, J2.2, J2.5, J2.6, J2.9, J2.10, J3.1, J3.2, J3.7, J3.8, J4.1, J4.2, J4.3, J4.4, J4.5, J4.6, JP1.2 (B), JP2.3 (B), JP3.3 (B), M1.1, M2.1, M3.1, M4.1, R22.1, U1.10 (GND), U1.25 (GND), U2.2 (GND); also elsewhere on the board
unnamed: C4.2, R11.1
unnamed: D1.2 (A), R6.2
unnamed: D2.2 (A), R5.2
unnamed: D3.2 (A), R4.2
unnamed: D4.2 (A), R3.2
unnamed: D5.2 (A), R7.2
unnamed: J1.A5 (CC1), U1.1 (CC1DB), U1.2 (CC1)
unnamed: J1.B5 (CC2), U1.4 (CC2), U1.5 (CC2DB)
unnamed: J1.A6 (D+), J1.B6 (D+), J5.1
unnamed: J1.A7 (D-), J1.B7 (D-), J5.2
unnamed: Q2.4 (G), R10.2, R11.2, R12.1
unnamed: C2.1, U1.21 (VREG_1V2)
unnamed: C1.1, U1.23 (VREG_2V7)
VBUS: C6.1, C8.1, J1.A4/B9 (VBUS), J1.B4/A9 (VBUS), Q2.1 (S), Q2.2 (S), Q2.3 (S), R9.1, R10.1, U1.24 (VDD), U2.1 (VI)
VCC: C7.1, JP2.1 (A), JP3.2 (C), R1.1, R13.1, R14.1, R15.1, R16.1, R17.1, R18.1, R19.1, R20.1, R21.1, R22.2, U1.22 (VSYS)
VDC: C4.1, J3.3, J3.4, J3.5, J3.6, Q2.5 (D), Q2.6 (D), Q2.7 (D), Q2.8 (D), R8.1; also elsewhere on the board

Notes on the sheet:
I don't want to use LDO to power external parts, because there would be large power loss when it is in 20V mode. Therefore, internal 3v3 LDO can be used only for pullups and LEDs
External power voltage must be within 3v - 5v5.
In case of unconnected JP3, disable second power option. PD sink will be active only when it is powered from USB
Power selector
USB-C connector and PD-sink controller
Addr selector
Mounting holes
I2C connector and pull-ups
Signal pull-ups
Connectors
LED indicators
LDO for internal purposes
Output disconnector

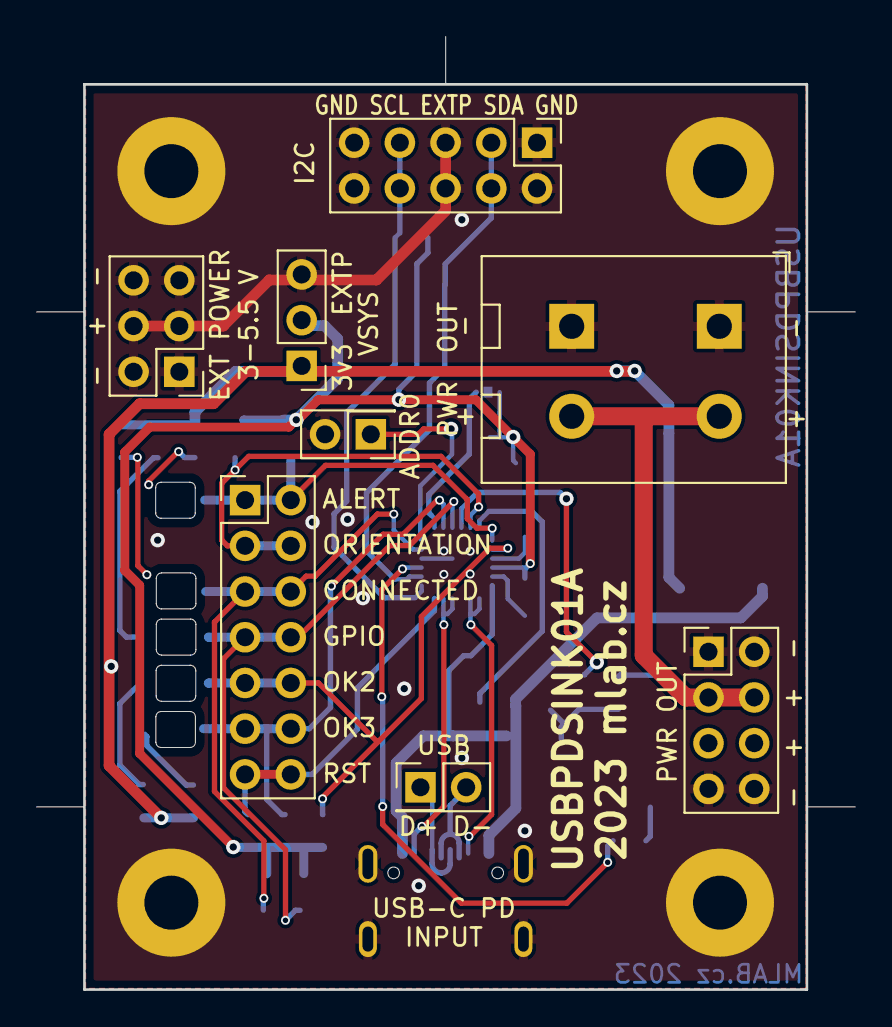
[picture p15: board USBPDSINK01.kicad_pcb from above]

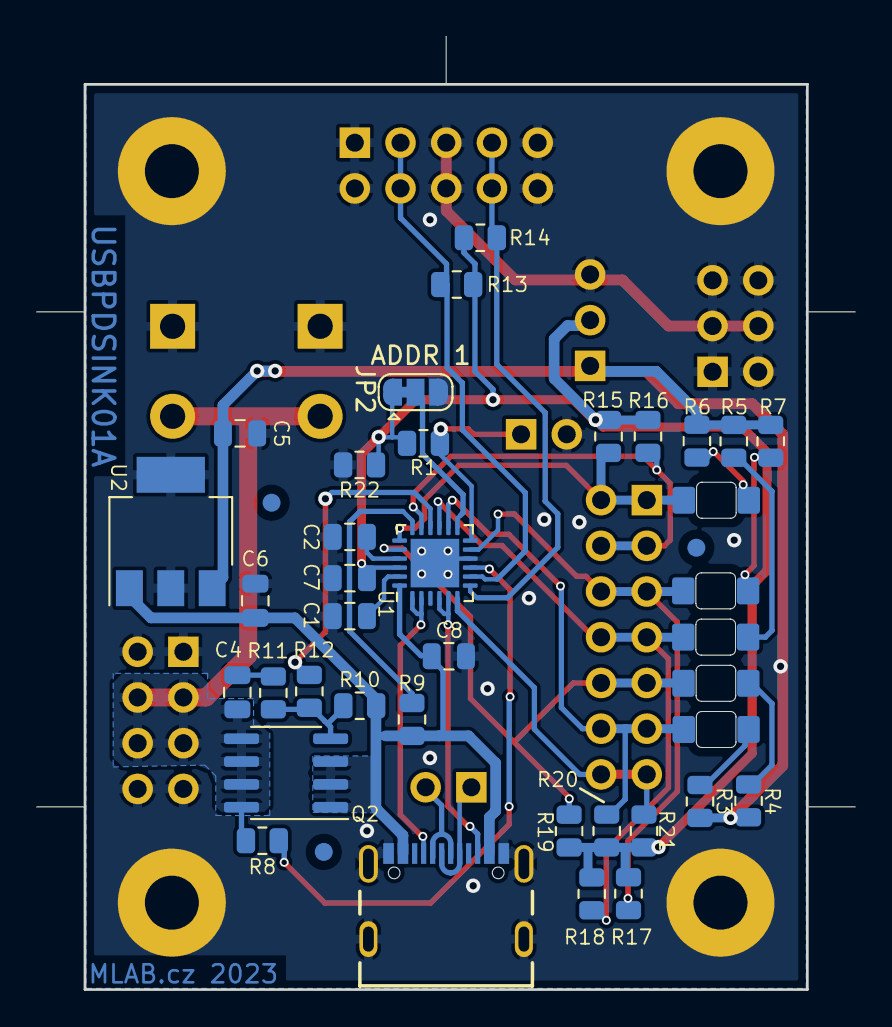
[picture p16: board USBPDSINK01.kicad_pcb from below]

Board: 2 copper layers, 40.1 x 50.3 mm, 53 parts (41 on the bottom side), 32 nets.

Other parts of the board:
J7: WAGO_2604-3102; TerminalBlock_WAGO_2604-3102_1x02_P5.00mm_Vertical

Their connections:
GND: J7.1; also elsewhere on the board
VDC: J7.2; also elsewhere on the board

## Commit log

2023-08-22 initial commit of USBPDSINK01
    [USBPDSINK01.kicad_pcb, USBPDSINK01.kicad_sch]
2023-08-23 Navrh schema
    [USBPDSINK01.kicad_pcb, USBPDSINK01.kicad_sch]
2023-08-23 Update actions products
    [USBPDSINK01-B_Adhesive.dxf, USBPDSINK01-B_Courtyard.dxf, USBPDSINK01-B_Cu.dxf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]
2023-08-23 update improvements in schematics and layout
    [USBPDSINK01.kicad_pcb, USBPDSINK01.kicad_sch]
2023-08-23 update component values
    [USBPDSINK01.kicad_sch]
2023-08-23 solve DRC
    [USBPDSINK01.kicad_pcb]
2023-08-23 update wago connector
    [USBPDSINK01.kicad_pcb, USBPDSINK01.kicad_sch]
2023-08-23 set sheet template
    [USBPDSINK01.kicad_pcb, USBPDSINK01.kicad_sch]
2023-09-06 minor updates in layout, clean schematics, add components MFPN
    [USBPDSINK01.kicad_pcb, USBPDSINK01.kicad_sch]
2023-09-06 version uploaded to aisler
    [USBPDSINK01.kicad_pcb, USBPDSINK01.kicad_sch]
2023-09-07 Update title block.
    [USBPDSINK01.kicad_sch]
2023-09-07 Cleanup traces.
    [USBPDSINK01.kicad_pcb]
2023-09-20 add ustid, change LDO
    [USBPDSINK01.kicad_pcb, USBPDSINK01.kicad_sch]
2023-09-22 Kontrola a priprava PCB na vyrobu
    [USBPDSINK01.kicad_pcb, USBPDSINK01.kicad_sch]
2023-09-24 Kontrola, upravi pred vyrobou
    [USBPDSINK01.kicad_pcb]
2023-10-04 Edit B.Fab
    [USBPDSINK01.kicad_pcb]
